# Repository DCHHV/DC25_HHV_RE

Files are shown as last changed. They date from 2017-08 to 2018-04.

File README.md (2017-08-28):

# DC25 HHV Reverse Engineering Challenge

## Info
DC25 Hardware Hacking Village Reverse Engineering Challenge

This repo contains all of the sources, eagle files, and gerbers for the DEF CON 25 Hardware Hacking Village Reverse Engineering Challenge.

Do not go any further than this if you do not wish to see spoilers.  The eagle/ folder has all of the PCB files in it, the gerbers or .brd file can be sent off to a fab house to create a PCB if you wish to re-create the challenge yourself.  The .hex file in the top folder is the binary blob that can be programmed in to the microcontroller.

Writeup available in docs/writeup.txt

BOM available in eagle/DC25_HHV_RE-A-BOM.txt

## Instructions

Once you have a kit in-hand, (if you don't yet, go to the HHV and pick one up!) there are two steps to be aware of for this challenge.

The first challenge, is to reverse engineer the schematic of the device itself.  Grab a piece of paper, draw up the schematic, and take it to the HHV.  A correct schematic will earn you a small prize (while available).

The meat of the challenge is the function of the device.  It's locked, find the passcode to unlock it; when unlocked the green LED will remain solid.  There are multiple ways to accomplish this task.  If you are stuck or just not sure how to proceed, come on down to the HHV and ask for help.  Once the device has been unlocked, make your way back to the HHV again to collect a larger prize (while available).

This challenge is meant to be fun for all levels of experience, but is designed to be an introduction to reverse engineering and a demonstration in how insecure some devices really are.

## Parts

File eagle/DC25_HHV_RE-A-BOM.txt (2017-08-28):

Partlist exported from /home/karl/my_codes/DC25_HHV_RE/eagle/DC25_HHV_RE-A.sch at 28 Aug 2017 13:11:10

Qty Value           Device          Package         Parts              Description                
1   .1uF            C-EU050-024X044 C050-024X044    C1                 CAPACITOR, European symbol 
2   100             R-US_0207/10    0207/10         R5, R6             RESISTOR, American symbol  
4   10k             R-US_0207/10    0207/10         R1, R2, R3, R4     RESISTOR, American symbol  
4   B3F-10XX        10-XX           B3F-10XX        S1, S2, S3, S4     OMRON SWITCH               
1   BAT-HLD-001-THM BAT-HLD-001-THM BAT-HLD-001-THM BT1                                           
1   PIC12F1571      PIC12F1571      DIL8            U1                 PIC12F1571/2               
1   Green           LED5MM          LED5MM          LED1               LED                        
1   Red             LED5MM          LED5MM          LED2               LED

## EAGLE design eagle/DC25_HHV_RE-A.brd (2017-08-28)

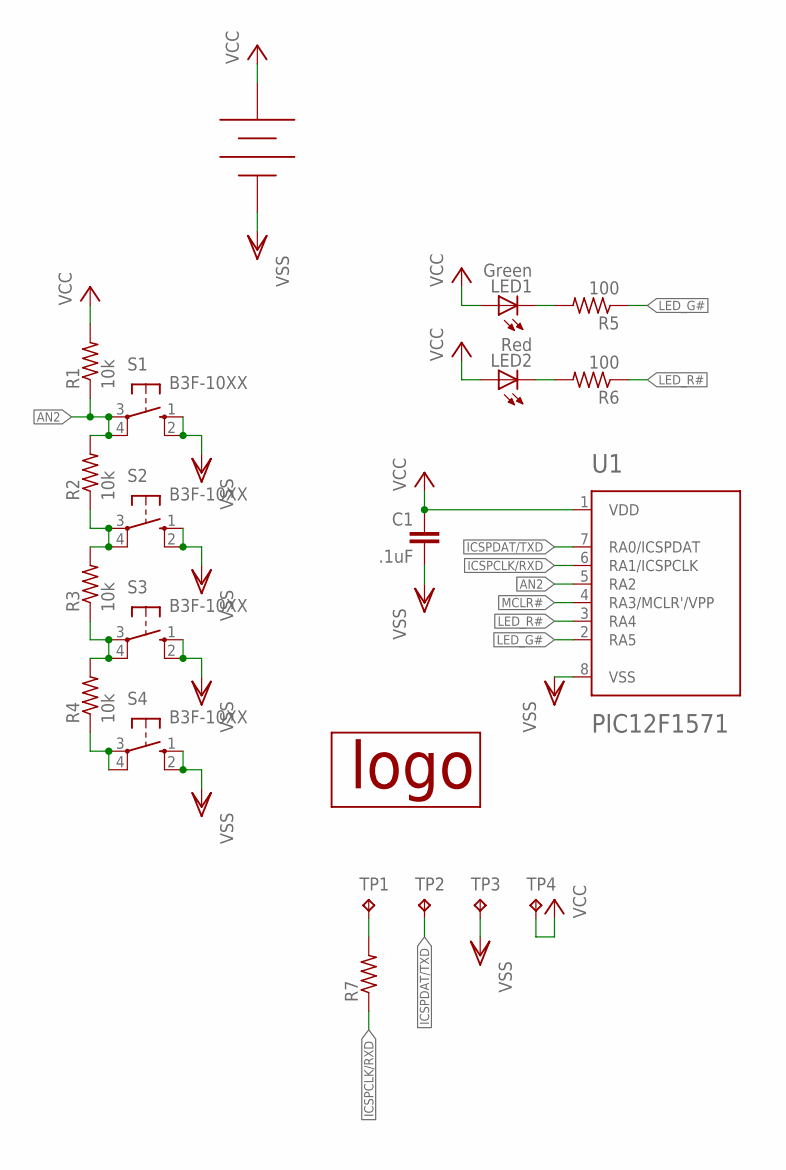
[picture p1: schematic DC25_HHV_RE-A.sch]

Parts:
BT1: BAT-HLD-001-THM
C1: .1uF; C050-024X044
LED1: Green; LED5MM
LED2: Red; LED5MM
R1, R2, R3, R4: 10k; 0207/10
R5, R6: 100; 0207/10
R7: R-US_R0402; R0402
S1, S2, S3, S4: B3F-10XX
TP1, TP2, TP3, TP4: TPTP13R; TP13R
U1: PIC12F1571; DIL8
U$1: KBELOGO-SILK

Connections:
AN2: R1.1, R2.2, S1.3, S1.4 (P1), U1.5 (RA2)
ICSPCLK/RXD: R7.1, U1.6 (RA1/ICSPCLK)
ICSPDAT/TXD: TP2.TP, U1.7 (RA0/ICSPDAT)
LED_G#: R5.1, U1.2 (RA5)
LED_R#: R6.1, U1.3 (RA4)
MCLR#: U1.4 (RA3/MCLR'/VPP)
unnamed: R4.1, S4.3, S4.4 (P1)
unnamed: R3.1, R4.2, S3.3, S3.4 (P1)
unnamed: LED2.K (C), R6.2
unnamed: R7.2, TP1.TP
unnamed: R2.1, R3.2, S2.3, S2.4 (P1)
unnamed: LED1.K (C), R5.2
VCC: BT1.+@0 (VCC), BT1.+@1 (VCC), BT1.+@2 (VCC), BT1.+@3 (VCC), C1.1, LED1.A, LED2.A, R1.2, TP4.TP, U1.1 (VDD)
VSS: BT1.- (VSS), C1.2, S1.1 (S), S1.2 (S1), S2.1 (S), S2.2 (S1), S3.1 (S), S3.2 (S1), S4.1 (S), S4.2 (S1), TP3.TP, U1.8 (VSS)

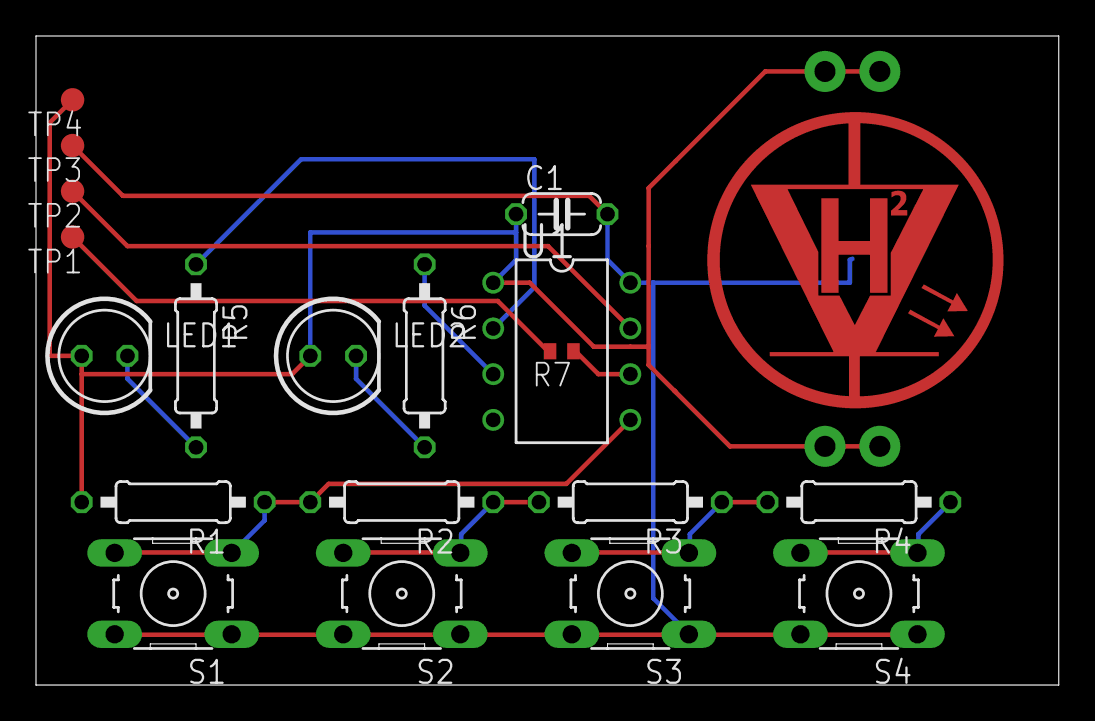
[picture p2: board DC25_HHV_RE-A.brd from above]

Board: 2 copper layers, 56.8 x 36.1 mm, 21 parts (1 on the bottom side), 13 nets.

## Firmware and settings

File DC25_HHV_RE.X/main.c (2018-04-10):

/* MIT License
 *
 * Copyright (c) 2017 KBEmbedded and DEF CON Hardware Hacking Village
 *
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
 * THE SOFTWARE IS PROVIDED "AS IS", WITHOUT WARRANTY OF ANY KIND, EXPRESS OR
 * IMPLIED, INCLUDING BUT NOT LIMITED TO THE WARRANTIES OF MERCHANTABILITY,
 * FITNESS FOR A PARTICULAR PURPOSE AND NONINFRINGEMENT. IN NO EVENT SHALL THE
 * AUTHORS OR COPYRIGHT HOLDERS BE LIABLE FOR ANY CLAIM, DAMAGES OR OTHER
 * LIABILITY, WHETHER IN AN ACTION OF CONTRACT, TORT OR OTHERWISE, ARISING FROM,
 * OUT OF OR IN CONNECTION WITH THE SOFTWARE OR THE USE OR OTHER DEALINGS IN THE
 * SOFTWARE.
 */



/*
 * Basic pinmap reference
 * RA0: TXD
 * RA1: RXD
 * RA2: Analog button input
 * RA3: Unused
 * RA4: Red LED#
 * RA5: Green LED#
 */

#include <xc.h>

//#define ECHO_UART             // Uncomment to enable echo of recv'ed chars

#define _XTAL_FREQ 16000000   // Oscillator frequency.

#pragma config FOSC = INTOSC  // INTOSC oscillator: I/O function on CLKIN pin.
#pragma config WDTE = OFF     // Watchdog Timer disable.
#pragma config PWRTE = OFF    // Power-up Timer enbable.
#pragma config MCLRE = ON     // MCLR/VPP pin function is MCLR.
#pragma config CP = OFF       // Program memory code protection disabled.
#pragma config BOREN = ON     // Brown-out Reset enabled.
#pragma config CLKOUTEN = OFF // CLKOUT function is disabled; I/O or oscillator function on the CLKOUT pin.
#pragma config WRT = OFF      // Flash Memory Write protection off.
#pragma config STVREN = ON    // Stack Overflow or Underflow will cause a Reset.
#pragma config BORV = LO      // Brown-out Reset Voltage (Vbor), low trip point selected.
#pragma config LVP = OFF      // High-voltage on MCLR/VPP must be used for programming.

#include <stddef.h>
#include <stdio.h>
#include <stdint.h>
#include <stdlib.h>
#include <string.h>

volatile uint8_t uart_byte;
volatile uint8_t adc_byte;
volatile bit adc_flag;
volatile bit uart_flag;
volatile bit blink_flag;
volatile bit newline_flag;
bit did_something = 0;  //Global so it is optimized with other bits
bit unlocked;
unsigned char cmdstring[9] = {0};
uint8_t kpbytes[9];
uint8_t kpcnt;

/* Cheaper than #defines */
const uint8_t LED_R = 4;
const uint8_t LED_G = 5;

void init_pic() {
  OSCCON = 0b01111010; // 16 Mhz oscillator.
  ANSELA = 0b00000100; // Analog enable on RA2 for button input
  TRISAbits.TRISA2 = 1;
  
  /* LEDs as outputs, active low */
  PORTAbits.RA4 = 1;
  PORTAbits.RA5 = 1;
  TRISAbits.TRISA4 = 0;
  TRISAbits.TRISA5 = 0;
}

void init_uart() {
  TRISAbits.TRISA1 = 1; // UART RX pin an input.
  TRISAbits.TRISA0 = 0; // UART TX pin an output.

  // 9600 bps, 16 MHz oscillator.
  SPBRGH = 0x01;
  SPBRGL = 0xA0;

  // 16-bit Baud Rate Generator
  BAUDCONbits.BRG16 = 1;

  TXSTAbits.TXEN = 1; // Transmit enabled.
  TXSTAbits.SYNC = 0; // Enable asynchronous mode.
  TXSTAbits.BRGH = 1; // High speed.

  RCSTAbits.SPEN = 1; // Enable serial port.

}

void init_adc(void) {
    /* ANSEL/TRIS already set by init_pic() */
    
    /* Set channel selection, AN2 */
    ADCON0bits.CHS = 0b00010;
    
    /* Set VREF to VDD */
    ADCON1bits.ADPREF = 0;
    
    /* Set conversion clock, Fosc/64, ~4 us conversion time */
    ADCON1bits.ADCS = 0b110;
    
    /* 10-bit left-justified */
    ADCON1bits.ADFM = 0;
    
    /* Enable ADC */
    ADCON0bits.ADON = 1;
    
    /* Enable ADC conversion interrupt */
    PIR1bits.ADIF = 0;
    PIE1bits.ADIE = 1;
    
    /* Enable timed conversion, ~10ms, from Timer0 */
    ADCON2bits.TRIGSEL = 0b0011;
    
    adc_flag = 0;
}

/* Set up Timer0 with 1:128 prescaler
 * At 16 MHz, this is roughly 8.2 ms, a close enough timing for ADC
 */
void init_timer0(void) 
{
    TMR0 = 0;
    OPTION_REGbits.PSA = 0;
    OPTION_REGbits.PS = 0b110;
    OPTION_REGbits.TMR0CS = 0;
}

void putch(unsigned char byte) {
  // Wait until no char is being held for transmission in the TXREG.
  while (!PIR1bits.TXIF) {
    continue;
  }
  // Write the byte to the transmission register.
  TXREG = byte;
}

void interrupt interrupt_handler() {
  if (PIR1bits.RCIF && PIE1bits.RCIE) {
    // EUSART receiver enabled and unread char in receive FIFO.
    if (RCSTAbits.OERR) {
      // Overrun error.
      RCSTAbits.CREN = 0;          // Clear the OERR flag.
      uart_byte = RCREG; // Clear any framing error.
      RCSTAbits.CREN = 1;
    } else {
      uart_byte = RCREG;
      if(uart_byte == '\r') newline_flag = 1;
      else uart_flag = 1;
    }
  }
  
  /* ADC, PIR1bits.ADIF must be manually cleared*/
  if (PIR1bits.ADIF && PIE1bits.ADIE) {
      PIR1bits.ADIF = 0;
      adc_byte = ADRESH;
      adc_flag = 1;
  }
}

void led_blink(uint8_t led) {
    LATA ^= (uint8_t)(1 << led);
    __delay_ms(50);
    LATA ^= (uint8_t)(1 << led);
}

void led_toggle(uint8_t led) {
    LATA ^= (uint8_t)(1 << led);
}

void parsecmd(void) 
{
        uint8_t cnt;

        if (!strcmp(cmdstring, "help")) {
            printf("Available commands:\r\n");
            printf("help\r\n");
            printf("ledtest\r\n");
            printf("Listing of debug commands is disabled\r\n");
            did_something = 1;
        }
        
        if (!strcmp(cmdstring, "ledtest")) {
            for(cnt = 10; cnt != 0; cnt--) {
                led_blink(LED_G);
                led_blink(LED_R);
            }
            did_something = 1;
        }

        if (!strcmp(cmdstring, "lockit")) {
            LATA |= (uint8_t)(1 << LED_G);
            unlocked = 0;
            did_something = 1;
        }
        
        if (!strcmp(cmdstring, "unlockit")) {
            LATA &= ~(uint8_t)(1 << LED_G);
            unlocked = 1;
            did_something = 1;
        }
        
        if(!did_something) {
            printf("Unknown command\r\n");
        }
        did_something = 0;
}

/* I think the best math for this will be 8 "chars", 4 inputs, 4096 total, 8^4
 * combinations.  If I focus on short timeout between attempts, can thwart brute
 * forcing.  
 * 
 * Average input time is about 3 seconds with medium speed, for 8 digits
 * We assume a brute forcer has to go through 50% of the key space to get the 
 *   correct answer.
 * This means 2048 total guesses.
 * With 10 s padding after p/w input, this averages out to 7 hours, assuming the 
 *   above statements.*/
void kp_parse(uint8_t data) {
    static bit repeated;
    static bit valid_press;
    
    if (data < 0x40) data = '1';
    if (data < 0x95 && data > 0x3F) data = '2';
    if (data < 0xb4 && data > 0x94) data = '3';
    if (data < 0xe5 && data > 0xb3) data = '4';
    if (data > 0xe4) data = 0; //Released
    
    if (repeated && (kpbytes[kpcnt] == data)) {
        repeated = 0;
        valid_press = 1;
        led_toggle(LED_G);        
    } 
    
    if (!valid_press && data) {
        kpbytes[kpcnt] = data;
        repeated = 1;
    }
    
    if (valid_press && data == 0) {
        valid_press = 0;
        kpcnt++;
        led_toggle(LED_G);
    }
}

/* Compares the global kpbytes to *string
 * If any character is wrong, delay for 1 us, if correct, then delay 2 us
 * This becomes an exaggerated side channel timing attack.
 * 
 * HARD_MODE will delay differently based on correct or incorrect
 * !HARD_MODE will fail instantly on first incorrect character
 */
#ifdef HARD_MODE
uint8_t kp_compare(const unsigned uint8_t *string)
{
    uint8_t i;
    uint8_t success = 1;
    for (i = 0; i != 8; i++) {
        if (kpbytes[i] == *string++) {
            __delay_us(2);
        } else {
            __delay_us(1);
            success = 0;
        }
    }
    return success;
}
#else
/* Maybe run through the string in reverse just to throw people off? */
uint8_t kp_compare(const unsigned char *string)
{
    uint8_t i;
    for (i = 0; i != 8; i++) {
        if (kpbytes[i] != *string++) {
            return (uint8_t)0;
        }
        __delay_ms(1);
    }
    return (uint8_t)1;
}
#endif

int main() {
    uint8_t recvcnt = 0;
    uint8_t i;
    init_pic();
    init_uart();
    init_adc();
    init_timer0();

    __delay_ms(1000);
    printf("SecurLock mechanism\r\n");
    printf("Build Features: Pre-set pass, code protect, debug output disabled.\r\n");
    printf("Rev. 1.43.2.341.4\r\n");
    printf("Initializing\r\n");
    led_toggle(LED_R);
    __delay_ms(1000);
    putch('.');
    led_toggle(LED_R);
    __delay_ms(1000);
    putch('.');
    led_toggle(LED_R);
    __delay_ms(1000);
    putch('.');
    led_toggle(LED_R);
    __delay_ms(1000);
    printf("Starting ADC");
    led_toggle(LED_R);
    __delay_ms(1000);
    putch('.');
    led_toggle(LED_R);
    __delay_ms(1000);
    putch('.');
    led_toggle(LED_R);
    __delay_ms(1000);
    putch('.');
    led_toggle(LED_R);
    __delay_ms(1000);
    printf("Setting up serial line buffers");
    led_toggle(LED_R);
    __delay_ms(1000);
    putch('.');
    led_toggle(LED_R);
    __delay_ms(1000);
    putch('.');
    led_toggle(LED_R);
    __delay_ms(1000);
    led_toggle(LED_R);
    printf("\r\nSystem started\r\n");
    
    // Enable serial RX and general interrupts
    RCSTAbits.CREN = 1;
    INTCONbits.GIE = 1;
    INTCONbits.PEIE = 1;

    // Enable the receive interrupt.
    PIE1bits.RCIE = 1;

    uart_flag = 0;
    
    while (1) {
        if (uart_flag) {
#ifdef ECHO_UART
            putch(uart_byte);
#endif
            uart_flag = 0;
            if(recvcnt != 8) cmdstring[recvcnt++] = uart_byte;
        }
    
        if (adc_flag) {
            adc_flag = 0;
            kp_parse(adc_byte);
            
            /* If we have a full word input, check it, disable interrupts
             * Because this could be a long function and there is no reason
             * to leave them enabled anyway 
             */
            if (kpcnt == 8) {
                PIE1bits.ADIE = 0;
                PIE1bits.RCIE = 0;
                if (unlocked) {
                    if (kp_compare("41241342")) {
                        unlocked = 0;
                        LATA |= (uint8_t)(1 << LED_G);
                    } else {
                        for (i = 10; i != 0; i--) {
                            led_blink(LED_R);
                            __delay_ms(50);
                        }
                    }
                } else {
                    /* In case anyone thinks the arbitrary rev number is the code */
                    if (kp_compare("14323414")) {
                        printf("lol, nice try though!\r\n");
                    }
                    
                    if (kp_compare("33124121")) {
                        unlocked = 1;
                        LATA &= ~(uint8_t)(1 << LED_G);
                    } else {
                        for (i = 100; i != 0; i--) {
                            led_blink(LED_R);
                            __delay_ms(50);
                        }
                    }
                }
                
                /* Clear our the kpbyte buffer and re-enable ADC/UART RX */
                while (--kpcnt) kpbytes[kpcnt] = 0;
                
                PIR1bits.RCIF = 0;
                PIE1bits.RCIE = 1;
                
                PIR1bits.ADIF = 0;
                PIE1bits.ADIE = 1;
            }

        }
    
        if (newline_flag) {
            parsecmd();
        
            /* Clean up buffer and reset for next command */
            newline_flag = 0;
            while(recvcnt) cmdstring[--recvcnt] = 0;
        }
    }
  return (EXIT_SUCCESS);
}

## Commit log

2017-08-27 Addition of Eagle files Addition of Microchip files
    [DC25_HHV_RE-A.brd, DC25_HHV_RE-A.sch, DC25_HHV_RE-P1.brd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]
2017-08-28 Added BOM
    [DC25_HHV_RE-A.brd, DC25_HHV_RE-A.sch]
2018-04-10 Fixed bug where "unlockit" and "lockit" commands would set the locked flag, but not change the LED state for feedback
    [main.c]
